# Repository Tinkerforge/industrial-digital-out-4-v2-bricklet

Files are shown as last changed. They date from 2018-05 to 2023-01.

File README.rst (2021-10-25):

Industrial Digital Out 4 Bricklet 2.0
=====================================

This repository contains the firmware source code and the hardware design
files. The documentation generator configs can be found at
https://github.com/Tinkerforge/generators

Repository Content
------------------

software/:
 * examples/: Examples for all supported languages
 * build/: Compiled files
 * src/: Source code of firmware
 * Makefile: Makefile to build project

hardware/:
 * Contains KiCad project files and additionally schematics as PDF

datasheets/:
 * Contains datasheets for sensors and complex ICs that are used

Hardware
--------

The hardware is designed with the open source EDA Suite KiCad
(http://www.kicad.org). Before you are able to open the files,
you have to install the Tinkerforge kicad-libraries
(https://github.com/Tinkerforge/kicad-libraries). You can either clone
them directly in hardware/ or clone them in a separate folder and
symlink them into hardware/
(ln -s kicad_path/kicad-libraries project_path/hardware). After that you
can open the .pro file in hardware/ with KiCad and from there view and
modify the schematics and the PCB layout.

Software
--------

If you want to do your own Brick/Bricklet firmware development we highly
recommend that you use our build environment setup script and read the
tutorial (https://www.tinkerforge.com/en/doc/Tutorials/Tutorial_Build_Environment/Tutorial.html).

To compile the C code we recommend you to install the newest GNU Arm Embedded
Toolchain (https://launchpad.net/gcc-arm-embedded/+download).
You also need to install bricklib2 (https://github.com/Tinkerforge/bricklib2).

You can either clone it directly in software/src/ or clone it in a
separate folder and symlink it into software/src/
(ln -s bricklib_path/bricklib2 project_path/software/src/). Finally make sure to
have CMake installed (http://www.cmake.org/cmake/resources/software.html).

After that you can build the firmware by invoking make in software/.
The firmware (.zbin) can then be found in software/build/ and uploaded
with brickv (click button "Flashing" on start screen).

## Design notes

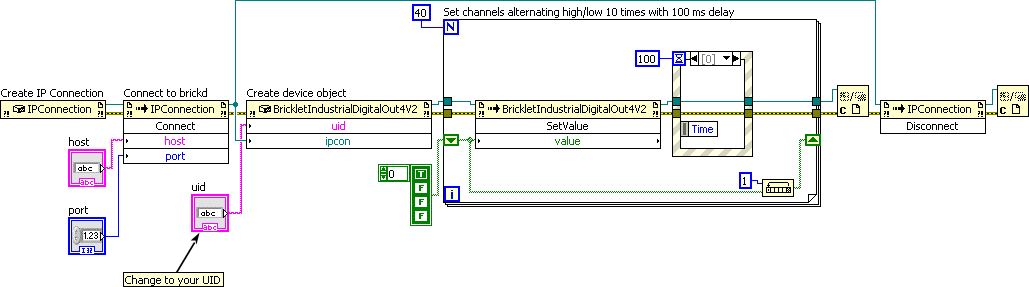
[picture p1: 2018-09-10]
software/examples/labview/Example Simple.vi.png

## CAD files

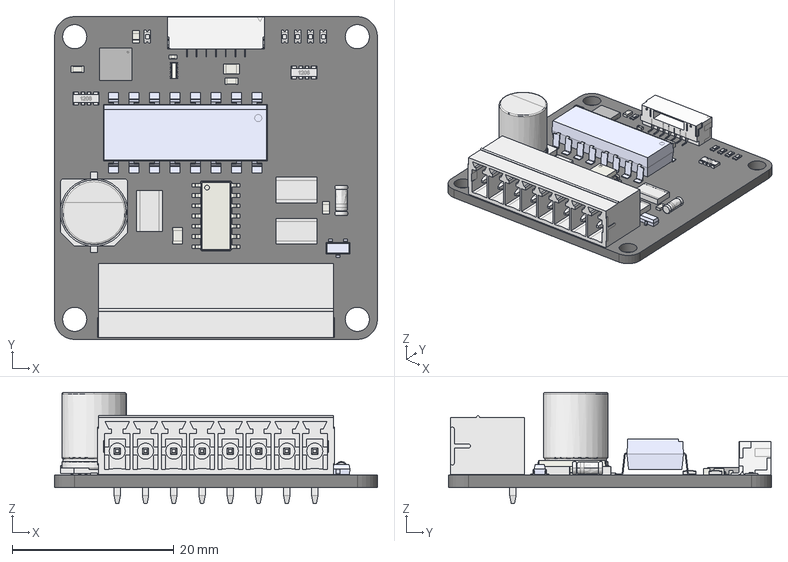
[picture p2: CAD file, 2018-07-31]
hardware/industrial-digital-out-4-v2.FCStd
40.0 x 40.0 x 13.8 mm
Pcb
QFN-24_4x4mm_Pitch0.5mm_
C_0805_
C_0805_001
c_elec_8x10_
C_0402_
C_0603_
C_0603_001
MiniMelf_
D_0603_blue_
D_0603_blue_001
D_0603_blue_002
D_0603_blue_003
D_0603_blue_004
BrickletConn_7pin_
8er_Phoenix_Buchse_
SOT23_
R_0603_
R_0603_001
R_4x0603_
R_4x1206_
R_4x1206_001
R_4x1206_002
R_4x0603_001
DIP-16_SMD_
soic_14_39x87_p127_

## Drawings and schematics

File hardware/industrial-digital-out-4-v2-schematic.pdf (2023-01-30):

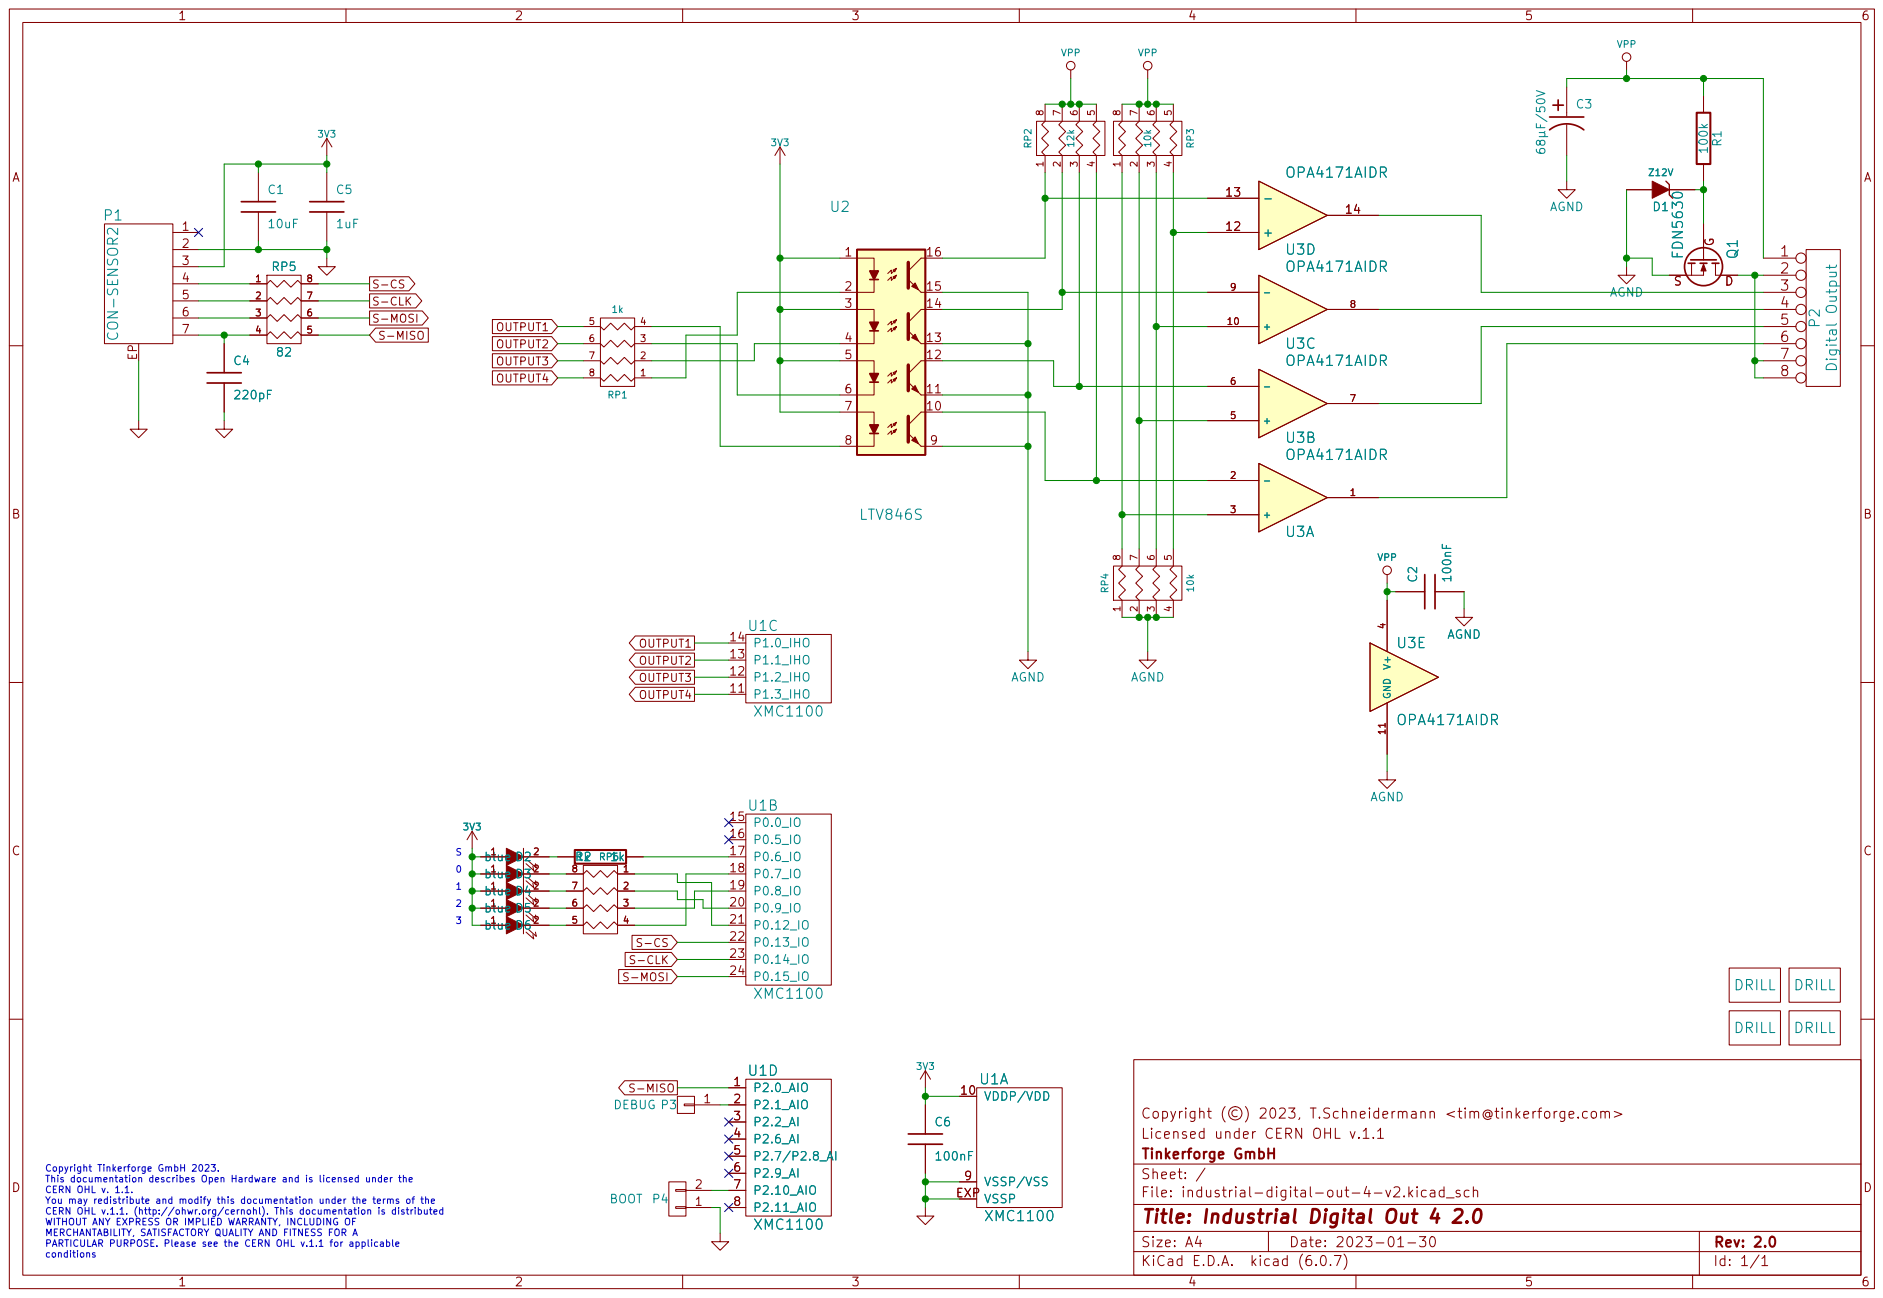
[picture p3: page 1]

7 7 | 2 2
6 6 | 3 3
5 5 | 4 4

3 Copyright Tinkerforge GmbH 2023. This documentation describes Open Hardware and is licensed under the CERN OHL v. 1.1. You may redistribute and modify this documentation under the terms of the CERN OHL v.1.1. (http://ohwr.org/cernohl). This documentation is distributed WITHOUT ANY EXPRESS OR IMPLIED WARRANTY, INCLUDING OF MERCHANTABILITY, SATISFACTORY QUALITY AND FITNESS FOR A

Licensed under CERN OHL v.1.1
File: industrial-digital-out-4-v2.kicad_sch Sheet: / Tinkerforge GmbH

Id: 1/1 Title: Industrial Digital Out 4 2.0

PARTICULAR PURPOSE. Please see the CERN OHL v.1.1 for applicable

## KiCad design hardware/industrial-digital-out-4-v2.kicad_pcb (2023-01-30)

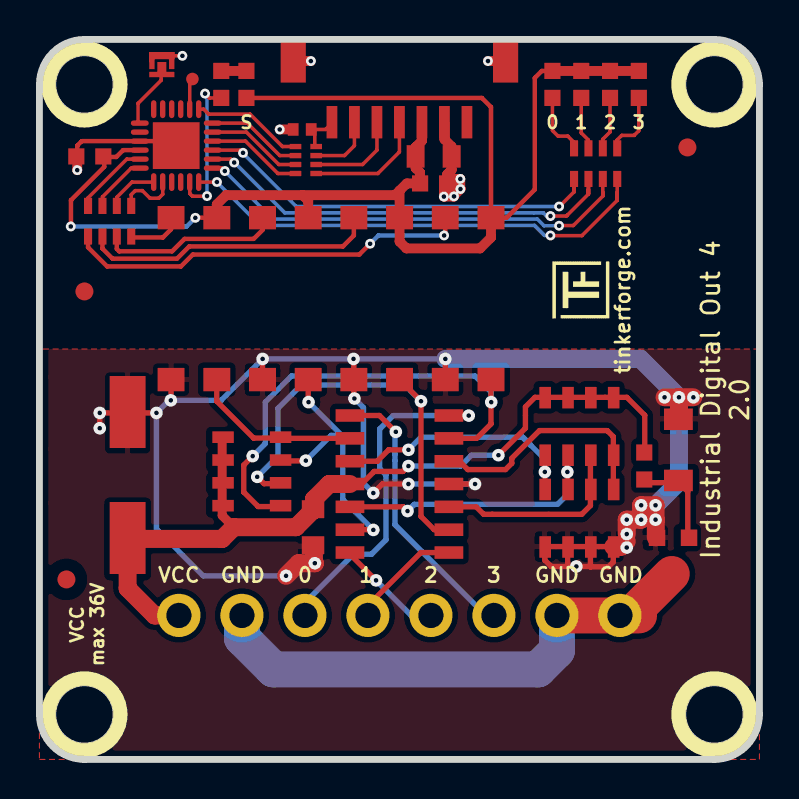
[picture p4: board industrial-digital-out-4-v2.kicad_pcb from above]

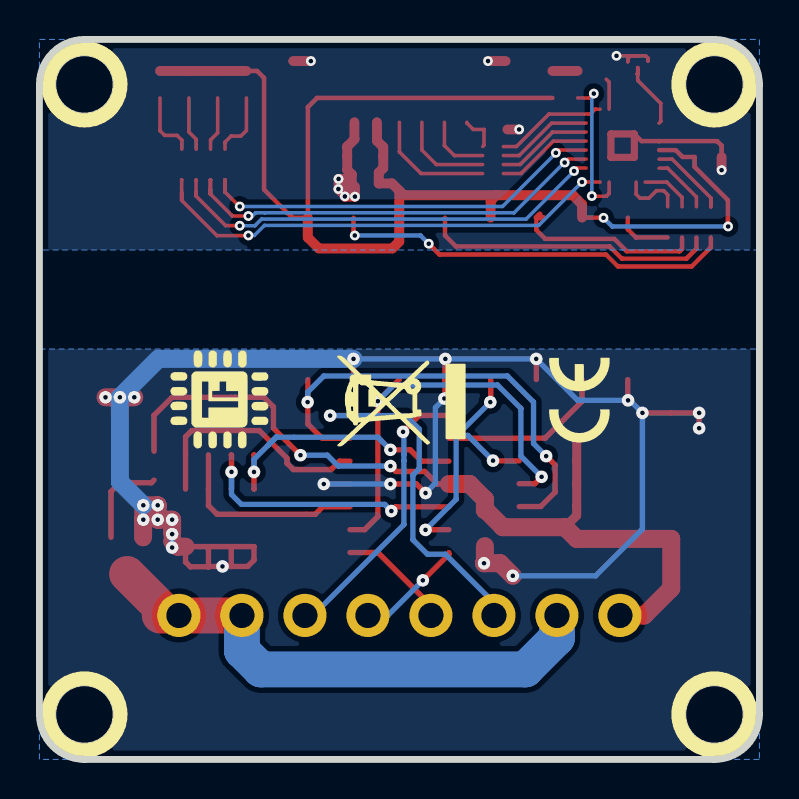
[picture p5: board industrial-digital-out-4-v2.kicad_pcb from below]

Board: 2 copper layers, 40.0 x 40.0 mm, 37 parts (2 on the bottom side), 46 nets.

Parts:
C1: 10uF; C0805
C2: 100nF; C0805
C3: 68µF/50V; ELKO_83
C4: 220pF; C0402F
C5: 1uF; C0603F
C6: 100nF; C0603F
D1: Z12V; MiniMelf
D2, D3, D4, D5, D6: blue; D0603F
Fiducial_Mark: VAL**; Fiducial_Mark
Fiducial_Mark#2, Fiducial_Mark#3: VAL**; Fiducial_Mark
P1: CON-SENSOR2
P2: Digital Output; OQ_8P
P3: DEBUG; DEBUG_PAD
P4: BOOT; SolderJumper
Q1: FDN5630; SOT23GDS
R1: 100k; R0603F
R2: 1k; R0603F
RP1, RP6: 1k; 0603X4
RP2: 12k; 1206X4
RP3, RP4: 10k; 1206X4
RP5: 82; 4X0402
U1: XMC1100; QFN24-4x4mm-0.5mm
U2: LTV846S; OPTO-SMD16
U3: OPA4171AIDR; SOP14
U4, U5, U6, U7: DRILL; DRILL_NP
VAL: WEEE_7mm
VAL#2: CE_5mm

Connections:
3V3: C1.1, C5.1, C6.1, D2.1, D3.1, D4.1, D5.1, D6.1, P1.3, U1.10, U2.1, U2.3, U2.5, U2.7
AGND: C2.2, C3.2, D1.1, Q1.S, RP4.1, RP4.2, RP4.3, RP4.4, U2.9, U2.11, U2.13, U2.15, U3.11
GND: C1.2, C4.2, C5.2, C6.2, P1.2, P1.EP, P4.1, U1.9, U1.EXP
unnamed: C4.1, P1.7, RP5.4
unnamed: D1.2, Q1.G, R1.2
unnamed: D2.2, R2.2
unnamed: D3.2, RP6.8
unnamed: D4.2, RP6.7
unnamed: D5.2, RP6.6
unnamed: D6.2, RP6.5
unnamed: P1.4, RP5.1
unnamed: P1.5, RP5.2
unnamed: P1.6, RP5.3
unnamed: P2.2, P2.7, P2.8, Q1.D
unnamed: P2.3, U3.14
unnamed: P2.4, U3.8
unnamed: P2.5, U3.7
unnamed: P2.6, U3.1
unnamed: P3.1, U1.2
unnamed: P4.2, U1.7
unnamed: R2.1, U1.17
unnamed: RP1.1, U2.2
unnamed: RP1.2, U2.4
unnamed: RP1.3, U2.6
unnamed: RP1.4, U2.8
unnamed: RP2.1, U2.16, U3.13
unnamed: RP2.2, U2.14, U3.9
unnamed: RP2.3, U2.12, U3.6
unnamed: RP2.4, U2.10, U3.2
unnamed: RP3.1, RP4.8, U3.3
unnamed: RP3.2, RP4.7, U3.5
unnamed: RP3.3, RP4.6, U3.10
unnamed: RP3.4, RP4.5, U3.12
unnamed: RP6.1, U1.21
unnamed: RP6.2, U1.20
unnamed: RP6.3, U1.19
unnamed: RP6.4, U1.18
OUTPUT1: RP1.5, U1.14
OUTPUT2: RP1.6, U1.13
OUTPUT3: RP1.7, U1.12
OUTPUT4: RP1.8, U1.11
S-CLK: RP5.7, U1.23
S-CS: RP5.8, U1.22
S-MISO: RP5.5, U1.1
S-MOSI: RP5.6, U1.24
VPP: C2.1, C3.1, P2.1, R1.1, RP2.5, RP2.6, RP2.7, RP2.8, RP3.5, RP3.6, RP3.7, RP3.8, U3.4

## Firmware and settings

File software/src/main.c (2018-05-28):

/* industrial-digital-out-4-v2-bricklet
 * Copyright (C) 2018 Ishraq Ibne Ashraf <ishraq@tinkerforge.com>
 *
 * main.c: Initialization for Industrial Digital Out 4 V2 Bricklet
 *
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
 * You should have received a copy of the GNU Lesser General Public
 * License along with this library; if not, write to the
 * Free Software Foundation, Inc., 59 Temple Place - Suite 330,
 * Boston, MA 02111-1307, USA.
 */

#include <stdio.h>
#include <stdbool.h>

#include "configs/config.h"

#include "bricklib2/bootloader/bootloader.h"
#include "bricklib2/hal/system_timer/system_timer.h"
#include "bricklib2/logging/logging.h"
#include "communication.h"

#include "ido4.h"

int main(void) {
	logging_init();
	logd("Start Industrial Digital Out 4 V2 Bricklet\n\r");

	communication_init();
	ido4_init();

	while(true) {
		bootloader_tick();
		communication_tick();
		ido4_tick();
	}
}

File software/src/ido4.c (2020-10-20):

/* industrial-digital-out-4-v2-bricklet
 * Copyright (C) 2018 Ishraq Ibne Ashraf <ishraq@tinkerforge.com>
 * Copyright (C) 2018-2020 Olaf Lüke <olaf@tinkerforge.com>
 *
 * ido4.h: Implementation of Industrial Digital Out 4 V2 Bricklet
 *
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
 * You should have received a copy of the GNU Lesser General Public
 * License along with this library; if not, write to the
 * Free Software Foundation, Inc., 59 Temple Place - Suite 330,
 * Boston, MA 02111-1307, USA.
 */

#include "ido4.h"

#include <stdint.h>
#include <stdbool.h>

#include "bricklib2/logging/logging.h"
#include "bricklib2/hal/system_timer/system_timer.h"
#include "bricklib2/utility/util_definitions.h"

#include "configs/config_ido4.h"
#include "communication.h"

#include "xmc_ccu4.h"

IDO4_t ido4;

XMC_CCU4_SLICE_t *const ido4_slice[IDO4_CHANNEL_NUM] = {
	CCU40_CC43,
	CCU40_CC42,
	CCU40_CC41,
	CCU40_CC40,
};

const uint8_t ido4_channel_pin[IDO4_CHANNEL_NUM] = {
	IDO4_CHANNEL_0_PIN,
	IDO4_CHANNEL_1_PIN,
	IDO4_CHANNEL_2_PIN,
	IDO4_CHANNEL_3_PIN,
};

XMC_GPIO_PORT_t *const ido4_channel_port[IDO4_CHANNEL_NUM] = {
	IDO4_CHANNEL_0_PORT,
	IDO4_CHANNEL_1_PORT,
	IDO4_CHANNEL_2_PORT,
	IDO4_CHANNEL_3_PORT,
};

const uint8_t ido4_channel_led_pin[IDO4_CHANNEL_NUM] = {
	IDO4_CHANNEL_LED_0_PIN,
	IDO4_CHANNEL_LED_1_PIN,
	IDO4_CHANNEL_LED_2_PIN,
	IDO4_CHANNEL_LED_3_PIN
};

XMC_GPIO_PORT_t *const ido4_channel_led_port[IDO4_CHANNEL_NUM] = {
	IDO4_CHANNEL_LED_0_PORT,
	IDO4_CHANNEL_LED_1_PORT,
	IDO4_CHANNEL_LED_2_PORT,
	IDO4_CHANNEL_LED_3_PORT,
};

void ido4_pwm_stop(const uint8_t channel) {
	if(ido4.channels[channel].pwm.frequency != 0) {
		ido4.channels[channel].pwm.duty_cycle = 0;
		ido4.channels[channel].pwm.frequency  = 0;
		XMC_CCU4_SLICE_StopTimer(ido4_slice[channel]);

		const XMC_GPIO_CONFIG_t pwm_stop_config	= {
			.mode                = XMC_GPIO_MODE_OUTPUT_PUSH_PULL,
			.input_hysteresis    = XMC_GPIO_INPUT_HYSTERESIS_STANDARD,
			.output_level        = XMC_GPIO_OUTPUT_LEVEL_LOW,
		};

		XMC_GPIO_Init(ido4_channel_port[channel], ido4_channel_pin[channel], &pwm_stop_config);
	}
}

void ido4_pwm_init(const uint8_t channel, const XMC_CCU4_SLICE_TIMER_REPEAT_MODE_t monoshot) {
	const XMC_CCU4_SLICE_COMPARE_CONFIG_t compare_config = {
		.timer_mode          = XMC_CCU4_SLICE_TIMER_COUNT_MODE_EA,
		.monoshot            = monoshot,
		.shadow_xfer_clear   = 0,
		.dither_timer_period = 0,
		.dither_duty_cycle   = 0,
		.prescaler_mode      = XMC_CCU4_SLICE_PRESCALER_MODE_NORMAL,
		.mcm_enable          = 0,
		.prescaler_initval   = 0,
		.float_limit         = 0,
		.dither_limit        = 0,
		.passive_level       = XMC_CCU4_SLICE_OUTPUT_PASSIVE_LEVEL_LOW,
		.timer_concatenation = 0
	};

	const XMC_GPIO_CONFIG_t pwm_config	= {
		.mode                = XMC_GPIO_MODE_OUTPUT_PUSH_PULL_ALT2,
		.input_hysteresis    = XMC_GPIO_INPUT_HYSTERESIS_STANDARD,
		.output_level        = XMC_GPIO_OUTPUT_LEVEL_LOW,
	};

	XMC_CCU4_Init(CCU40, XMC_CCU4_SLICE_MCMS_ACTION_TRANSFER_PR_CR);
	XMC_CCU4_StartPrescaler(CCU40);
	XMC_CCU4_SLICE_CompareInit(ido4_slice[channel], &compare_config);

	// Set the period and compare register values
	XMC_CCU4_SLICE_SetTimerPeriodMatch(ido4_slice[channel], 32000);
	XMC_CCU4_SLICE_SetTimerCompareMatch(ido4_slice[channel], 0);

	XMC_CCU4_EnableShadowTransfer(CCU40, (XMC_CCU4_SHADOW_TRANSFER_SLICE_0 << (ido4_channel_pin[channel]*4)) |
	                                     (XMC_CCU4_SHADOW_TRANSFER_PRESCALER_SLICE_0 << (ido4_channel_pin[channel]*4)));

	XMC_GPIO_Init(ido4_channel_port[channel], ido4_channel_pin[channel], &pwm_config);

	XMC_CCU4_EnableClock(CCU40, ido4_channel_pin[channel]);
}

void ido4_pwm_update(const uint8_t channel, const uint32_t frequency, const uint16_t duty_cycle) {
	if(frequency == 0) {
		ido4_pwm_stop(channel);
		return;
	}

	const bool new_start = ido4.channels[channel].pwm.frequency == 0;

	if(new_start) {
		ido4_pwm_init(channel, XMC_CCU4_SLICE_TIMER_REPEAT_MODE_REPEAT);
	}

	ido4.channels[channel].pwm.duty_cycle = MIN(10000, duty_cycle);
	ido4.channels[channel].pwm.frequency  = MIN(320000000, frequency);

	uint32_t prescaler = 0;
	uint32_t divisor = 1;
	uint32_t period_value = (640000000/ido4.channels[channel].pwm.frequency) - 1;
	while(period_value > 0xFFFF) {
		prescaler++;
		divisor *= 2;
		period_value = (640000000/(ido4.channels[channel].pwm.frequency*divisor)) - 1;
	}

	uint32_t compare_value = (period_value*duty_cycle + 10000/2)/10000;

	XMC_CCU4_SLICE_SetPrescaler(ido4_slice[channel], prescaler);
	XMC_CCU4_SLICE_SetTimerPeriodMatch(ido4_slice[channel], period_value);
	XMC_CCU4_SLICE_SetTimerCompareMatch(ido4_slice[channel], compare_value);
	XMC_CCU4_EnableShadowTransfer(CCU40, (XMC_CCU4_SHADOW_TRANSFER_SLICE_0 << (ido4_channel_pin[channel]*4)) |
    		                             (XMC_CCU4_SHADOW_TRANSFER_PRESCALER_SLICE_0 << (ido4_channel_pin[channel]*4)));

	if(new_start) {
    	XMC_CCU4_SLICE_StartTimer(ido4_slice[channel]);
	}
}

void ido4_init(void) {
	logd("[+] IDO4-V2: ido4_init()\n\r");

	// Channel out config
	XMC_GPIO_CONFIG_t ch_pin_out_config = {
		.mode         = XMC_GPIO_MODE_OUTPUT_PUSH_PULL,
		.output_level = XMC_GPIO_OUTPUT_LEVEL_HIGH,
	};

	// Initialise all the channels
	for(uint8_t i = 0; i < IDO4_CHANNEL_NUM; i++) {
		// Generic channel config
		ido4.channels[i].value = false;

		XMC_GPIO_Init(ido4_channel_port[i], ido4_channel_pin[i], &ch_pin_out_config);
		XMC_GPIO_SetOutputHigh(ido4_channel_port[i], ido4_channel_pin[i]);

		// Channel monoflop config
		ido4.channels[i].monoflop.time = 0;
		ido4.channels[i].monoflop.time_start = 0;
		ido4.channels[i].monoflop.time_remaining = 0;
		ido4.channels[i].monoflop.running = false;

		XMC_GPIO_Init(ido4_channel_led_port[i], ido4_channel_led_pin[i], &ch_pin_out_config);
	
		ido4.channels[i].status_led.config = INDUSTRIAL_DIGITAL_OUT_4_V2_CHANNEL_LED_CONFIG_SHOW_CHANNEL_STATUS;
		ido4.channels[i].status_led.channel_led_flicker_state.config = LED_FLICKER_CONFIG_OFF;
	}

	// Monopflop callback ringbuffer init
	ringbuffer_init(&ido4.monoflop_cb_rb,
	                MONOFLOP_CB_BUFFER_SIZE,
	                &ido4.monoflop_cb_buffer[0]);
}
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

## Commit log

2018-01-17 Add schematic
    [industrial-do4.sch]
2018-01-17 Add pcb
    [industrial-do4.kicad_pcb]
2018-02-20 Cleanup KiCad libraries config
    Ensure LibDir=kicad-libraries and LibName1=tinkerforge.
    Remove special library.
2018-05-07 Rename files
    [industrial-digital-out-4-v2.kicad_pcb, industrial-digital-out-4-v2.sch]
2018-05-07 Adapt routing for status leds
    [industrial-digital-out-4-v2.kicad_pcb, industrial-digital-out-4-v2.sch]
2018-05-07 Change routing
    [industrial-digital-out-4-v2.kicad_pcb]
2018-05-16 drc check for prototype order
    [industrial-digital-out-4-v2.kicad_pcb]
2018-05-28 Firmware implementation
    [cmake_config_custom.txt]
2018-06-05 Add implementation of PWM API
2018-06-06 set origin
    [industrial-digital-out-4-v2.kicad_pcb]
2018-06-18 Change capacitor footprint(s) to C0402F
    [industrial-digital-out-4-v2.kicad_pcb, industrial-digital-out-4-v2.sch]
2018-07-17 specify processor
    [industrial-digital-out-4-v2.kicad_pcb, industrial-digital-out-4-v2.sch]
2018-07-31 Add 3d model (*.FCStd & *.step)
    [industrial-digital-out-4-v2.FCStd]
2020-02-26 drc and fixed board outline
    [industrial-digital-out-4-v2.kicad_pcb]
2020-09-02 uc: Add example driver note.
2021-10-25 Update KiCad link
    https://www.kicad.org/blog/2021/10/Avoid-links-to-former-kicad-domain/
2022-04-27 uc: Adapt to bindings changes
    [example_simple.c]
2023-01-30 Data Cleanup
    [industrial-digital-out-4-v2.kicad_pcb, industrial-digital-out-4-v2.kicad_sch, industrial-digital-out-4-v2.sch]

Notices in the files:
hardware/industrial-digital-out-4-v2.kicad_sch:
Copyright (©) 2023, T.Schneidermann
